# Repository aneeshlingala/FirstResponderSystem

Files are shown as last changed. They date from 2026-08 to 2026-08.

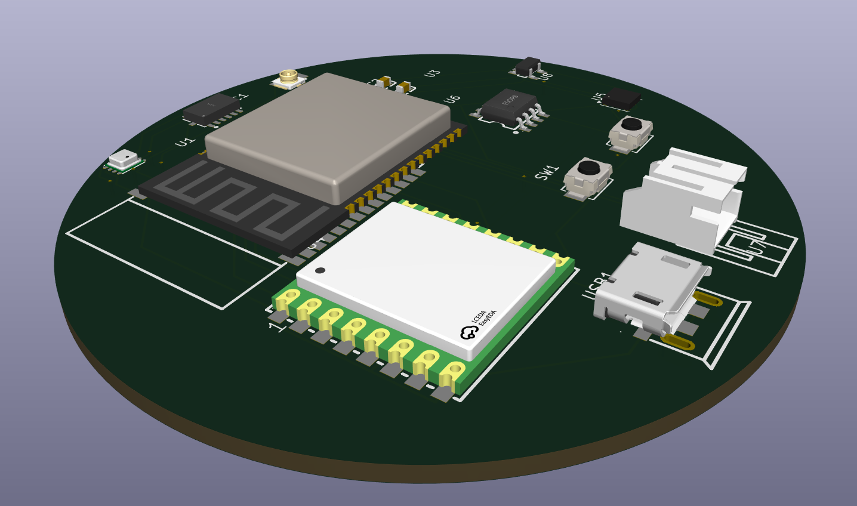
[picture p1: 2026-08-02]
environmentalnode/pcb_images/pcb3d.png

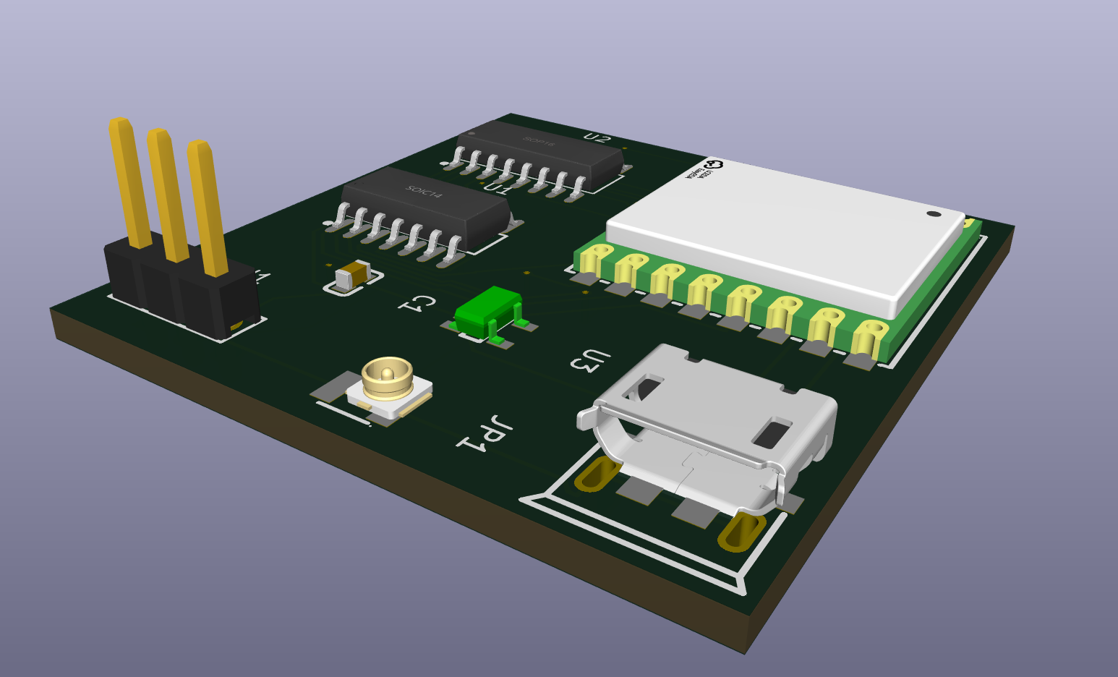
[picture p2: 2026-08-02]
broadcastnode/pcb_images/pcb3d.png

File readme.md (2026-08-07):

### Tech Report Link: [https://github.com/aneeshlingala/FirstResponderSystem/blob/main/tech_report_reverie_hacks_final.pdf](https://github.com/aneeshlingala/FirstResponderSystem/blob/main/tech_report_reverie_hacks_final.pdf)

# PROBLEM
During major disasters, first responders (police, fire, medical) do not have a reliable way to track their environment, find survivors, and receive information in real time. Existing systems can be expensive, hard to deploy, or require additional personnel to operate, wasting manpower that can be used from more urgent tasks.

# SOLUTION
The FirstResponderSystem uses cheap to manufacture, durable, and easy-to-deploy custom-made PCBs that create a centralized long-range radio network suited for emergencies instead of relying on broken or buggy connection systems (WiFi, Mobile Data, etc). By providing real-time sensor data and survivor detection, FirstResponderSystem allows emergency personnel to analyze dangerous conditions, locate any survivors, and make safe decisions while allowing responders to work on more urgent things. The data can also be sent to other organizations to relay information to people in the area, declare evacuations/emergencies, and more. The survivor node can be put in rubble to detect survivors, while the environmental node can be put in various parts of the disaster area. Multiple survivor and environmental nodes can be used at once. 

# CONTENTS OF GITHUB REPO
1. Survivor PCB
   * This PCB utilizes the cheap ATTINY16-14 MCU and utilizes Doppler Radars, Distance Sensors, and Infrared cameras to detect survivors trapped under rubble or other items. It broadcasts its data using an RFM95W LoRa transceiver (receiver and transmitter) on 915mHz. It is battery powered and uses a u.FL port for the antenna.

2. Environmental PCB
   * This PCB utilizes the cost-friendly ESP32 MCU and uses Bosch BME280 and BME680 Sensors to capture data about the environment. It also uses AQI, VOC, and other environmental sensors. It broadcasts its data using an RFM95W LoRa module on 915mHz, with a u.FL antenna port. It is battery powered.

3. Broadcast PCB
   * This PCB uses the cheap ATTINY16-14 MCU and receives data from the other two PCBS using the RFM95W LoRa transceiver. It takes the information received and sends it over Serial on Micro-USB to a computer to read. It is powered by the Micro-USB port.

4. Computer Software
   * The computer software includes a .py file for universal execution, as well as a .exe file generated by py2exe for quick use. The software is able to detect packets sent by the Broadcast PCB over serial and has an interface to select the COM port to read from. Once detected, it lists all the PCBS and shows info if you click on the names of the PCBS. It classifies the PCB as either ENV (environmental) or SRV (survivor detection). It shows all the info recorded by both PCBS. There is also a DEMO mode, which populates the user interface with "fake" broadcasting PCBS for showing at events or getting used to the interface.
  
# INFO

The PCBS were made in KiCAD 10 with footprints and symbols from LCSC, bundled KiCAD files, and SnapEDA.

All of the PCBS come with images:
* Image of the schematic
* Image of the PCB top-down
* Image of the PCB in 3D view

All of the PCBS come with code made in PlatformIO in VSCode. The programming language used to make the code is C++. The code successfully compiles with the firmware file in the .pio/build/[MCU NAME]/ and uses a good amount of 3rd-party libraries to interface with various components. 

The folders inside the survivornode, broadcastnode, or environmental node are structured as follows:
* The pcb_code folder includes the PCB Code written in C++.
* The pcb_images folder includes images of the schematic, PCB top-down, and the PCB in 3D.
* The pcb_data folder includes KiCAD files for opening the PCB in KiCAD. It also includes the Bill of Materials (BOM) and component positions CSV as well as the Gerber files in a zip.

The computer_code folder has a reciever.exe file for running on Windows without any dependencies being required to be installed. The reciever.py file can be run universally and requires Tkinter (already installed on most Python distributions), pyserial, and Python 3.13+ to run.

# WHAT I LEARNED
I learned how to make PCBs in KiCad 10 with proper symbols and footprints. I also learned how to use the design and electrical rules checker to make sure my project met all of the rules.

# CHALLENGES I FACED
Some challenges I faced included having issues with footprint/symbol quality, finding proper footprints for some of my component choices, and exporting gerbers. I solved these issues by searching up solutions online and using external plugins to export gerbers properly since it was bugged out with LCSC symbols. 

# DIAGRAM
DiagramFirstResponderSystem

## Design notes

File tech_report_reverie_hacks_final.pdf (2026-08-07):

Reverie Hacks 2026 Submission - Embedded Systems: https://github.com/aneeshlingala/FirstResponderSystem

## 1. Introduction

Abstract:
The FirstResponderSystem is an affordable LoRa based sensor network that allows first responders (police, fire, medical) to quickly find survivors and monitor their environment and hazards without relying on spotty or weak Wi-Fi or cell infrastructure.

The Problem:
During major disasters, first responders do not have a reliable way to track their environment, find survivors, and receive information in real time. A report from the Federal Communications Commission (FCC) during 2018 showed that natural disasters like Hurricanes Irma and Maria took down over 95% of cell infrastructure, affecting vital systems such as 911 call centers (Federal Communications Commission, 2018). Existing systems can be expensive, hard to deploy, or require additional personnel to operate, wasting manpower that can be used from more urgent tasks.

The Solution:
The FirstResponderSystem uses inexpensive, durable, and easy-to-deploy custom-made PCBs that create a centralized long-range radio network suited for emergencies instead of relying on broken or buggy connection systems (WiFi, Mobile Data, etc). LoRa has been shown to maintain good connectivity around ~3km in dense, suburban areas with an antenna mounted only a few meters off the ground (Augustin et al., 2016). By providing real-time sensor data and survivor detection, FirstResponderSystem allows emergency personnel to analyze dangerous conditions, locate any survivors, and make safe decisions while allowing responders to work on more urgent things. The data can also be sent to other organizations to relay information to people in the area, declare evacuations/emergencies, and more. The survivor node can be put in rubble to detect survivors, while the environmental node can be put in various parts of the disaster area. Multiple survivor and environmental nodes can be used at once.

Node Architecture Diagram:

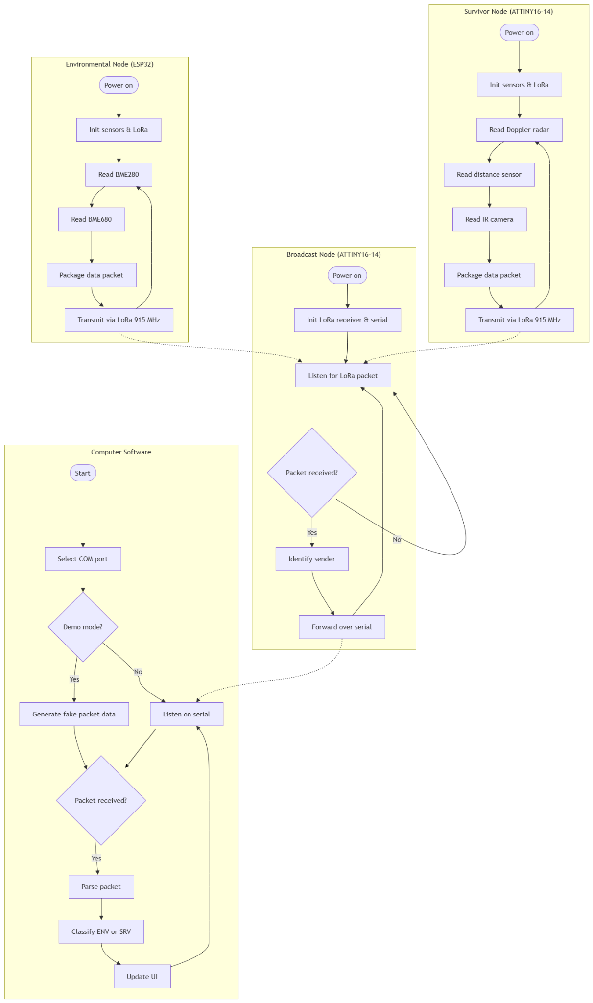
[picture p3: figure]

## 2.System Architecture

PCB and Software Interaction:
FirstResponderSystem runs as a centralized sensor network with three different hardware nodes and computer software to analyze the data. The system utilizes LoRa radios to transceive information without relying on WiFi or cell towers which may fail.
1. Survivor Node (SRV) and Environmental Node (ENV): The Survivor Node and Environmental Node operate by themselves with a battery. Multiple Survivor and Environmental nodes can be deployed in the disaster region. Survivor Nodes can be placed into rubble where survivors may be trapped, while Environmental Nodes can be deployed anywhere with an open area. Each node gets sensor readings, interprets and analyzes the data, makes a data packet, and transmits the data over the 915mHz band.
2. Broadcast Node: The Broadcast Node connects to a computer over Micro-USB to power itself and send data. Only one Broadcast Node can be deployed. It utilizes a LoRa radio transceiver to receive data packets from other independent nodes and uses a serial to USB converter to send data to the computer it is connected to.
3. Computer Software: The computer software acts as the layer between the data packets and human-readable information. It listens to serial packets sent by the Broadcast Node on a COM port, parses every packet and classifies it as SRV or ENV with the node’s randomly-generated identification number. It maintains a list of alerts and information from each node to be able to view the readings. The software also includes a “DEMO” mode, where the user interface is populated with fake nodes to show the functionalities of the software and let the users get acquainted with the interface.

Node Requirements:
Survivor and Environmental Nodes are required to be in range of the broadcast node to properly work. The computer software can alert if a node is having connection problems. New nodes can be added without needing to configure anything, allowing for quick deployment of more nodes if required.

## 3.Communication Specifications

Radio Specs:
All three nodes utilize the RFM95W LoRa transceiver (receiver + transmitter) with the Semtech SX1276 chipset. The LoRa radio technology was chosen because it had low power usage and long range when compared to WiFi or cellular.
﹣ Frequency: 915 mHz in ISM band
﹣ Transmit Power: +2 dBm to +20 dBm
﹣ Spreading Factor (higher - longer range, slower transmission, vice versa): SF9
﹣ Expected Range: 5-20km (depends on tuning)
﹣ Data Rate: ~1.8 kbps
﹣ Antenna: u.FL (https://en.wikipedia.org/wiki/Hirose_U.FL) connector to attach an antenna
﹣ Survivor Node Packet Format: RSSI:<rssi>,SNR:<snr>,DATA:ID:<node_id>,X:<x>,Y:<y> ,Z:<z>,M:<motion>,P:<presence>,D:<distance>,H:<huma n>
﹣ Environmental Node Packet Format: RSSI:<rssi>,SNR:<snr>,DATA:Node ID:<node_id>,Temp:<temp>,Pressure:<pressure>,Humidi ty:<humidity>,X gyro:<x>,Y gyro:<y>,Z gyro:<z>,Gas temp:<gas_temp>,VOC:<voc>

## 4.Software

Computer Software Info:
The computer software (client) is built for Python 3.11+ and utilizes Tkinter for the GUI part of the client. It uses pyserial to interface with the COM ports and receive serial data. It can be used without needing to install dependencies on Windows computers when the .exe is run. The .exe was built with py2exe. For usage on other operating systems, the .py file can be used. However, there needs to be Python 3.11+, Tkinter (provided with most Python software distributions), and the pyserial module installed.

Serial Reader:
A background process called serial_reader opens the selected COM port at 115200 baud rate. Each line from the serial input is pushed onto an info queue and is refreshed to show on the screen every 300ms.

Packet Parsing:
Each line utilizes a comma delimitated format. The software is able to differentiate node type by the start of the packet, where it either says it is under ENV (environmental) or SRV (survivor). This keeps the data format more human-readable when debugging is required.

Node Tracking:
Each node’s sensor data is saved in memory, allowing for a rolling history of sensor outputs. The sensor data is either shown in text or in a live chart to the user. Nodes are either in the online state, stale state (no packet in 15sec), or offline state (no packet in 60sec). These switching states allow for capturing and reading accurate data and alerts.

Alerts:
The software has three varying levels of alerts: info, warning, and critical. These alerts can be triggered by human presence detection, RSSI (signal strength) dropping below -95dBm, or a node going stale or offline.

Demo Mode:
Demo mode runs a thread that simulates realistic data packets for various simulated nodes. The data packets are populated with randomly-generated info, allowing for demos of the software without having nodes on hand.

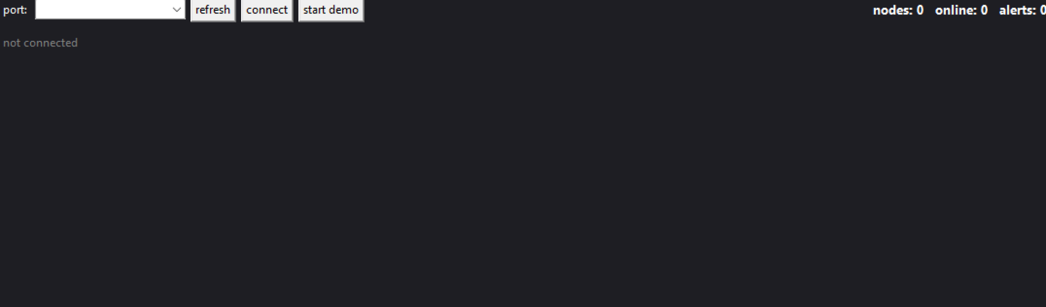
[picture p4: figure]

## 5.PCB Design

Details:
All of the three nodes were custom-designed in KiCAD 10 as a double layer board. The footprints and symbols used in the PCBs were from LCSC, already bundled in KiCAD, or RCWL/SnapEDA.

Survivor Node PCB:
﹣ MCU: ATTINY16-14
﹣ Key Components: Doppler radar, distance sensor, IR camera, and RFM95W LoRa transceiver
﹣ Size: 75 x 56mm
﹣ Power: Battery-powered Li-ion
﹣ Cost: $11-12 per PCB + parts cost

Environmental Node PCB:
﹣ MCU: ESP32
﹣ Key components: BME280, BME680, and RFM95W LoRa transceiver
﹣ Size: Circular - 62.17 x 62.17mm
﹣ Power: Battery-powered Li-ion
﹣ Cost: $7-8 per PCB + parts cost

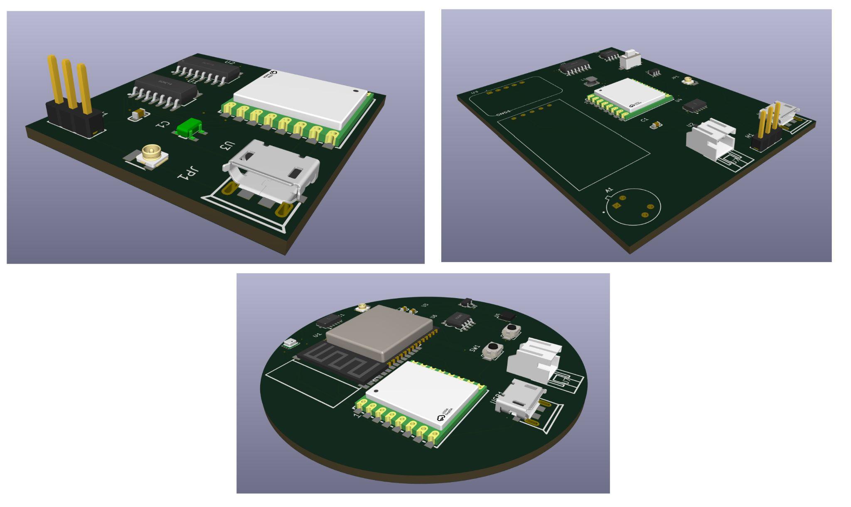
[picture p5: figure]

Broadcast Node PCB:
﹣ MCU: ATTINY16-14
﹣ Key components: RFM95W LoRa transceiver, and Micro-USB port ﹣ Size: 34.76 x 35.98mm
﹣ Power: Micro-USB Port
﹣ Cost: $5.50-7.00 per PCB + parts cost

Design Considerations:
For the MCU, the ATTINY16-14 was chosen for the Survivor Node because it was a chip that could last long on batteries while still being able to get proper data from its sensors. For the environmental node, the ESP32 was chosen because it had better compatibility and power for more complex sensors, while still conserving battery. For the Broadcast Node, the ATTINY16-14 was chosen because the components and purpose of the PCB were simple

## 6.Testing

Status:
As of now, this project has been digitally tested and validated in every phase that doesn’t require PCB fabrication.

What has been validated:
﹣ Schematic and layout was tested using KiCAD’s electrical rules checker
﹣ PCB was tested using KiCAD’s design rules checker
﹣ Computer software was tested by sending packets matching the expected format over serial
﹣ Firmware code was able to compile and could fit under the flash storage limit of the MCU

What needs to be done:
﹣ Fabrication and assembly of the PCBS (either by hand-soldering or PCBA)
﹣ LoRa range testing
﹣ Packet reliability over varying distances
﹣ Battery life testing

## 7.Sustainability and Scalability

Cost and Deployment:
Each PCB is very inexpensive to make (about $1-2 per PCB - excluding parts), making FirstResponderSystem much affordable to deploy at scale compared to other similar systems like SAR equipment or thermal drones. Nodes are also redeployable if they aren’t too damaged.

Network Scalability:
FirstResponderSystem utilizes a star topology, so new Survivor and Environmental Nodes can be added to the system without needing a full system reconfiguration or restart. The system runs on a two-second transmit interval and runs at SF9 spreading factor, allowing one broadcast node to receive data from dozens of nodes without slowing down or getting too overloaded.

Environmental Impact:
The nodes were programmed to only transmit briefly and infrequently compared to having a constant connection to WiFi networks or cell towers. This way of sending packets allows the nodes to conserve power and maintain a low RF footprint. Since components are soldered, either by stencil or by hand, bad or damaged components can be replaced rather than discarding the whole node.

## 8. Programming

Firmware Language and Tools Used:
All three nodes were programmed in C++ using PlatformIO Arduino in Visual Studio Code. The code is organized with its own platformio.ini, source code files, and libraries. The code was verified to compile successfully and fit within the boundaries of the flash storage size.

Fitting within flash storage boundaries:
The Survivor and Broadcast nodes run on the ATTINY16-14 MCU, which only has 16 KB of flash. Few vendor libraries were too big to fit when compiled with the LoRa and sensor libraries. A few examples of these libraries included RadioLib (on some nodes) and the MLX90640 library. To combat this issue, the SX1276 library was used instead of RadioLib to directly interface with the chip, and it was lighter since it did not carry configurations for other chips. Similarly, the MLX90640 library was replaced with a custom I2C driver integrated into the code that interfaced with registers to work, rather than pulling full driver libraries like other libraries would do. This method was utilized because disabling specific parts of libraries in platformio.ini was breaking dependencies and library functionality overall, especially for RadioLib. Manual string-building was also used to save flash storage rather than using heavy string libraries.

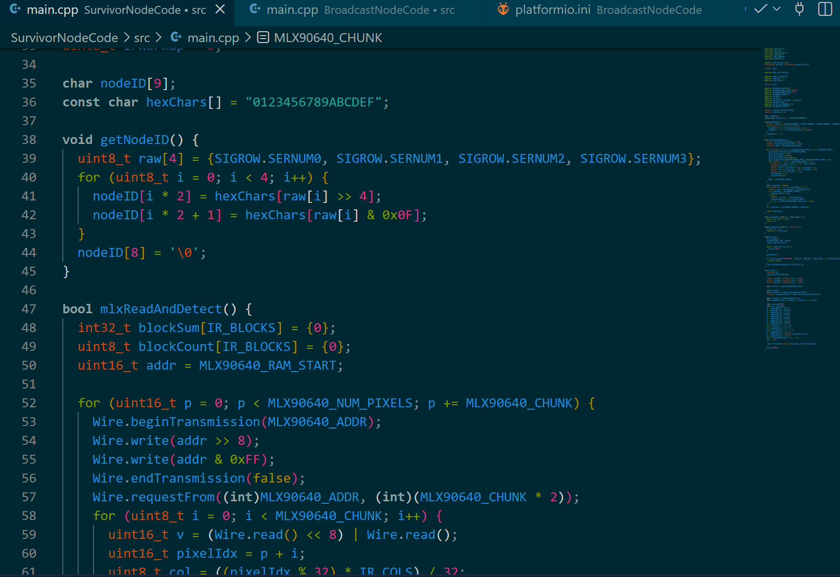
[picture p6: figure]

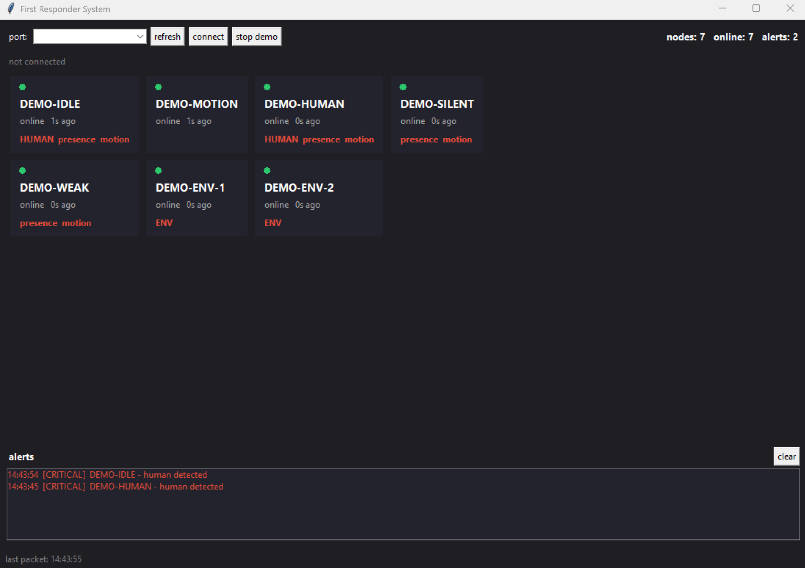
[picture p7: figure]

## 9. User Experience and Design

Computer Software UI:
Since first responders need to interpret data quickly under stressful conditions, the software’s user interface (UI) was designed to be human-readable and viewable at-a-glance while still preserving information. Another principle that was used in the creation of the UI was that a first responder should be able to tell the condition and alerts from a node, without needing to parse the sensor values themselves.

At-a-glance Status:
In the UI box of a node, a color-coded status (online, stale, offline) is shown so connection issues can be noticed without reading logs or timestamps. Alerts are also classified with three levels, with info, warning, and critical. This allows a first responder to quickly locate a major issue without digging through a list of other issues or logs.

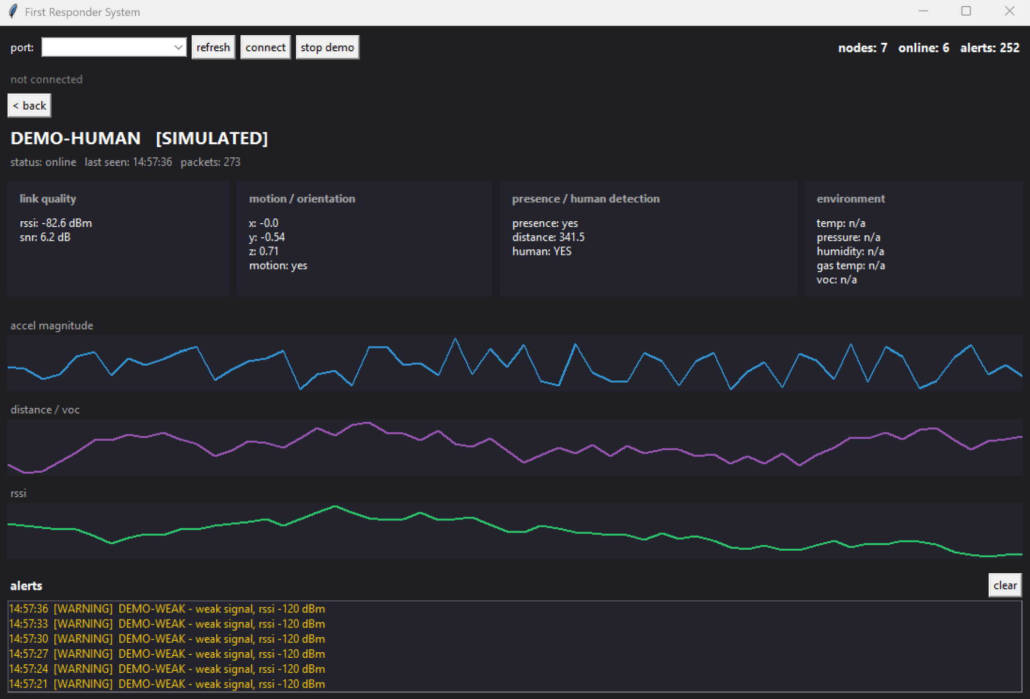
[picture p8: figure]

No Configuration Required:
New nodes are able to automatically join the list in the computer once they are detected. Since information is sent over serial and the nodes utilize a star-topology, there is no need to waste time setting up nodes, naming the nodes, or manually pairing. Nodes can easily be added on-the-fly without needing any special technicians or specialized people, since they automatically generate a name from information in the MCU’s fuses.

No-Hardware Preview:
Demo mode in the computer software allows first responders or judges to get familiar with the interface. Demo mode populates the interface with “fake” nodes that send randomly-generated packets to simulate disasters/incidents. This mode can also show the software at events without needing systems or nodes on hand.

## 10. Future Improvements

Things to be done:
- Data Logging - Save incoming packets into a database (online or locally) for future analysis

- Packet Resending - Make a node resend a packet if it was dropped or information was lost
- Encryption/Auth - Add authentication and encryption to the packets to keep information safe
- GPS - Add GPS to the Survivor and Environmental Nodes so that the nodes show detections on a map, not a list
- Mobile/Web interface - Expand the Tkinter interface to allow first responders to view info from a phone or web browser
- Adjust frequency based on region - Different countries and parts of the world use different frequencies for LoRa/unlicensed bands, so we need to ship different modems for each region of the world
- FCC Part 15 Compliance - Any deployment of the FirstResponderSystem would require compliance with FCC Part 15’s transmit power, duty cycle, and frequency hopping regulations

## 11. Team and Credits

Creator Info:
This project was designed, built, and recorded by Aneesh Lingala.

Acknowledgements (names ending in .h are C or C++ libraries):
- KiCAD for the PCB designing software
- Arduino.h - Arduino Core Team
- Wire.h - Arduino Core Team
- SX1276.h - Matthias Prinke
- ADXL345_WE.h - Wolfgang Ewald
- LD2410.h - Nick Reynolds
- Bosch_BME280_Arduino.h - Frank Häfele
- Zanshin_BME680.h - SV-Zanshin Arduino Org.
- Radiolib.h (Environmental Node) - Jan Gromeš
- WiFi.h (ESP32) - Espressif Systems
- PySerial (computer software) - Chris Liechti
- Tkinter (computer software) - Guido van Rossum and Steen Lumholt

Works Cited:

- Federal Communications Commission, Public Safety and Homeland Security Bureau. (2018). 2017 Atlantic hurricane season: Impact on communications report and recommendations (Public Safety Docket No. 17-344).
https://docs.fcc.gov/public/attachments/DOC-353805A1.pdf
- Augustin, A., Yi, J., Clausen, T., & Townsley, W. (2016). A study of LoRa: Long range & low power networks for the internet of things. Sensors, 16(9), 1466. https://doi.org/10.3390/s16091466

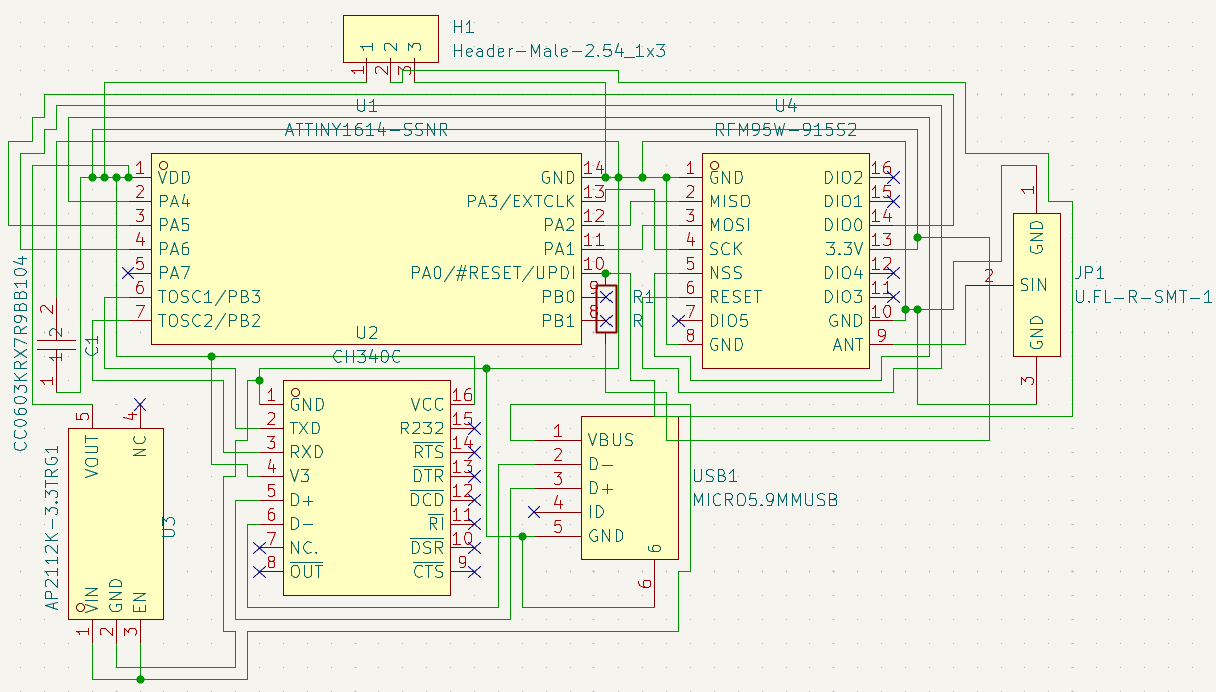
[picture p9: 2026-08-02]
broadcastnode/pcb_images/schematic.png

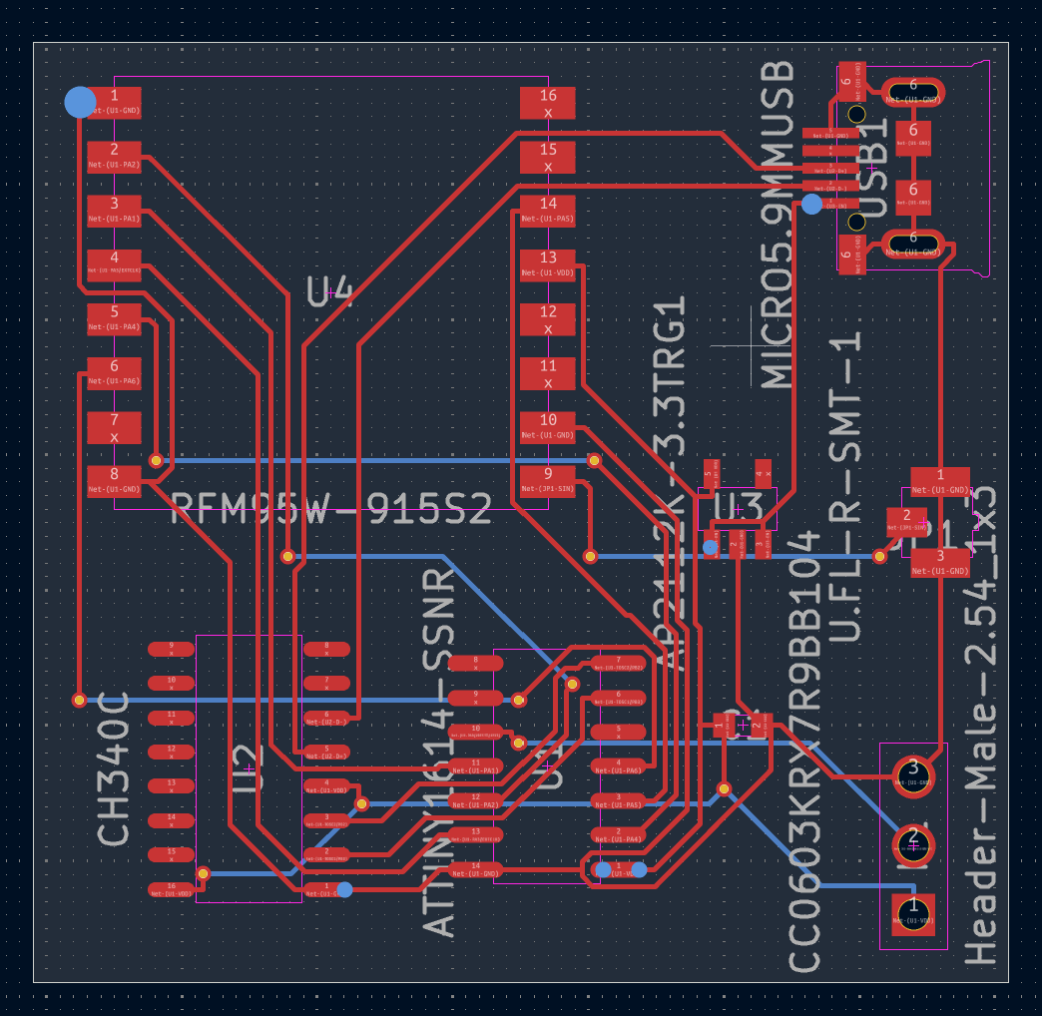
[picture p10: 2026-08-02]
broadcastnode/pcb_images/pcbtopdown.png

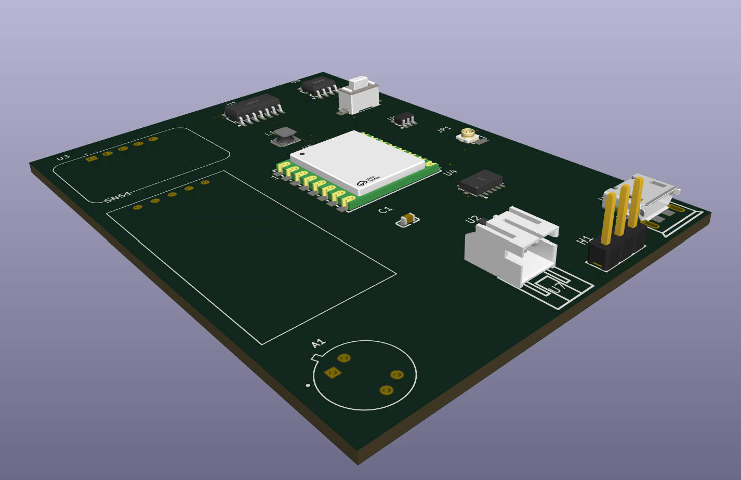
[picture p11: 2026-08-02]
survivornode/pcb_images/pcb3d.png

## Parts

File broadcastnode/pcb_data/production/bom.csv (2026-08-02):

Designator | Footprint | Quantity | Value | LCSC Part #
C1 | C0603 | 1 | CC0603KRX7R9BB104 | C14663
H1 | HDR-TH_3P-P2.54-V-M-1 | 1 | Header-Male-2.54_1x3 | C49257
JP1 | ANT-SMD_UFL-R-SMT-1-10 | 1 | U.FL-R-SMT-1 | C88373
U1 | SOIC-14_L8.7-W3.9-P1.27-LS6.0-BL | 1 | ATTINY1614-SSNR | C481364
U2 | SOP-16_L10.0-W3.9-P1.27-LS6.0-BL | 1 | CH340C | C84681
U3 | SOT-25-5_L2.9-W1.6-P0.95-LS2.8-BL | 1 | AP2112K-3.3TRG1 | C51118
U4 | WIRELM-SMD_16P-L16.0-W16.0-P2.00_LORA-CC68-915MHZ-TCXO | 1 | RFM95W-915S2 | C6760738
USB1 | MICRO-USB-SMD_5P-P0.65-H-F_MICRO5.9MMUSB | 1 | MICRO5.9MMUSB | C393940

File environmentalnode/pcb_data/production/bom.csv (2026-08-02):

Designator | Footprint | Quantity | Value | LCSC Part #
C1 | C0603 | 1 | CC0603KRX7R9BB104 | C14663
C2 | C0603 | 1 | CL10A105KB8NNNC | C15849
JP1 | ANT-SMD_UFL-R-SMT-1-10 | 1 | U.FL-R-SMT-1 | C88373
SW1, SW2 | SW-SMD_L3.9-W3.0-P4.45 | 2 | TS-1088-AR02016 | C720477
U1 | WIFI-SMD_ESP32-WROOM-32E | 1 | ESP32-WROOM-32E | C701342
U2 | LGA-8_BME280_BL | 1 | BME280 | C92489
U3 | LGA-14_L5.0-W3.0-P0.80-BL | 1 | ADXL345BCCZ-RL7 | C9667
U4 | WIRELM-SMD_16P-L16.0-W16.0-P2.00_LORA-CC68-915MHZ-TCXO | 1 | RFM95W-915S2 | C6760738
U5 | Bosch_LGA-8_3x3mm_P0.8mm_ClockwisePinNumbering | 1 | BME680
U6 | ESOP-8_L4.9-W3.9-P1.27-LS6.0-BL-EP | 1 | TP4056 | C16581
U7 | CONN-TH_S2B-PH-K-S-LF-SN | 1 | S2B-PH-K-S | C173752
U8 | SOT-25-5_L2.9-W1.6-P0.95-LS2.8-BL | 1 | AP2112K-3.3TRG1 | C51118
USB1 | MICRO-USB-SMD_5P-P0.65-H-F_MICRO5.9MMUSB | 1 | MICRO5.9MMUSB | C393940

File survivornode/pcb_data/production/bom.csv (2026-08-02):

Designator | Footprint | Quantity | Value | LCSC Part #
A1 | TO292P930H600-4 | 1 | MLX90640ESF-BAA-000-TU
C1 | C0603 | 1 | CL10A105KB8NNNC | C15849
H1 | HDR-TH_3P-P2.54-V-M-1 | 1 | Header-Male-2.54_1x3 | C49257
JP1 | ANT-SMD_UFL-R-SMT-1-10 | 1 | U.FL-R-SMT-1 | C88373
L1 | IND-SMD_L3.0-W3.0_FNR30XXS | 1 | FNR3015S2R2MT | C167747
SNS1 | RCWL-0516 | 1 | RCWL-0516
U1 | SOIC-14_L8.7-W3.9-P1.27-LS6.0-BL | 1 | ATTINY1614-SSNR | C481364
U2 | SOT-563_L1.6-W1.2-P0.50-LS1.6-BR | 1 | TPS61023DRLR | C919459
U3 | MODULE_HLK-LD2410C | 1 | HLK-LD2410C
U4 | LGA-14_L5.0-W3.0-P0.80-BL | 1 | ADXL345BCCZ-RL7 | C9667
U5 | WIRELM-SMD_16P-L16.0-W16.0-P2.00_LORA-CC68-915MHZ-TCXO | 1 | RFM95W-915S2 | C6760738
U6 | SW-SMD_L6.0-W3.5-LS8.0 | 1 | YZA-032-5.0W | C49108628
U7 | CONN-TH_S2B-PH-K-S-LF-SN | 1 | S2B-PH-K-S | C173752
U8 | ESOP-8_L4.9-W3.9-P1.27-LS6.0-BL-EP | 1 | TP4056 | C16581
U9 | SOT-25-5_L2.9-W1.6-P0.95-LS2.8-BL | 1 | AP2112K-3.3TRG1 | C51118
USB1 | MICRO-USB-SMD_5P-P0.65-H-F_MICRO5.9MMUSB | 1 | MICRO5.9MMUSB | C393940

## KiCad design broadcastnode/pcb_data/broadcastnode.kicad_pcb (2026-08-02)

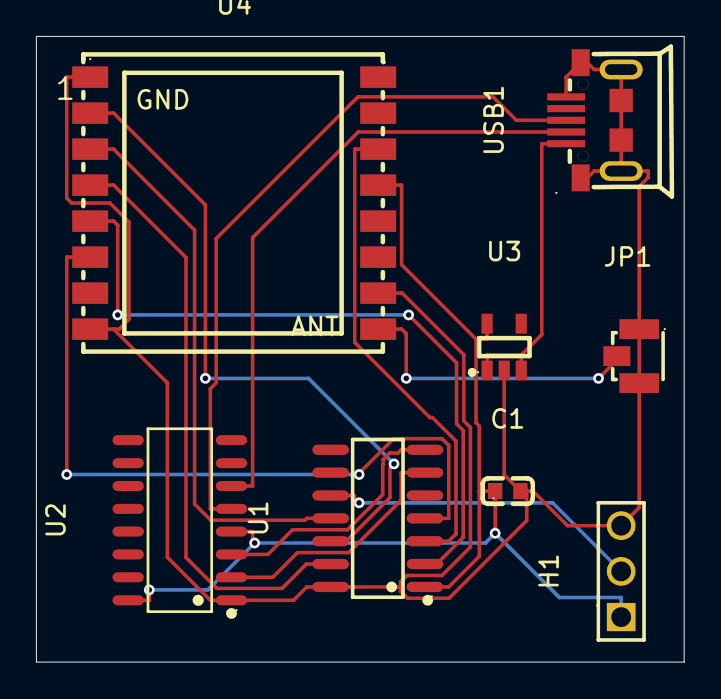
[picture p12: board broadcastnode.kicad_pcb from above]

Board: 2 copper layers, 36.0 x 34.8 mm, 8 parts (0 on the bottom side), 15 nets.

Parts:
C1: CC0603KRX7R9BB104; C0603
H1: Header-Male-2.54_1x3; HDR-TH_3P-P2.54-V-M-1
JP1: U.FL-R-SMT-1; ANT-SMD_UFL-R-SMT-1-10
U1: ATTINY1614-SSNR; SOIC-14_L8.7-W3.9-P1.27-LS6.0-BL
U2: CH340C; SOP-16_L10.0-W3.9-P1.27-LS6.0-BL
U3: AP2112K-3.3TRG1; SOT-25-5_L2.9-W1.6-P0.95-LS2.8-BL
U4: RFM95W-915S2; WIRELM-SMD_16P-L16.0-W16.0-P2.00_LORA-CC68-915MHZ-TCXO
USB1: MICRO5.9MMUSB; MICRO-USB-SMD_5P-P0.65-H-F_MICRO5.9MMUSB

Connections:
unnamed: JP1.2 (SIN), U4.9 (ANT)
unnamed: C1.2, H1.3, JP1.1 (GND), JP1.3 (GND), U1.14 (GND), U2.1 (GND), U3.2 (GND), U4.1 (GND), U4.8 (GND), U4.10 (GND), USB1.5 (GND), USB1.6
unnamed: H1.2, U1.10 (PA0/#RESET/UPDI)
unnamed: U1.11 (PA1), U4.3 (MOSI)
unnamed: U1.12 (PA2), U4.2 (MISO)
unnamed: U1.13 (PA3/EXTCLK), U4.4 (SCK)
unnamed: U1.2 (PA4), U4.5 (NSS)
unnamed: U1.3 (PA5), U4.14 (DIO0)
unnamed: U1.4 (PA6), U4.6 (RESET)
unnamed: U1.6 (TOSC1/PB3), U2.2 (TXD)
unnamed: U1.7 (TOSC2/PB2), U2.3 (RXD)
unnamed: C1.1, H1.1, U1.1 (VDD), U2.4 (V3), U2.16 (VCC), U3.5 (VOUT), U4.13 (3.3V)
unnamed: U2.5 (D+), USB1.3 (D+)
unnamed: U2.6 (D-), USB1.2 (D-)
unnamed: U3.1 (VIN), U3.3 (EN), USB1.1 (VBUS)

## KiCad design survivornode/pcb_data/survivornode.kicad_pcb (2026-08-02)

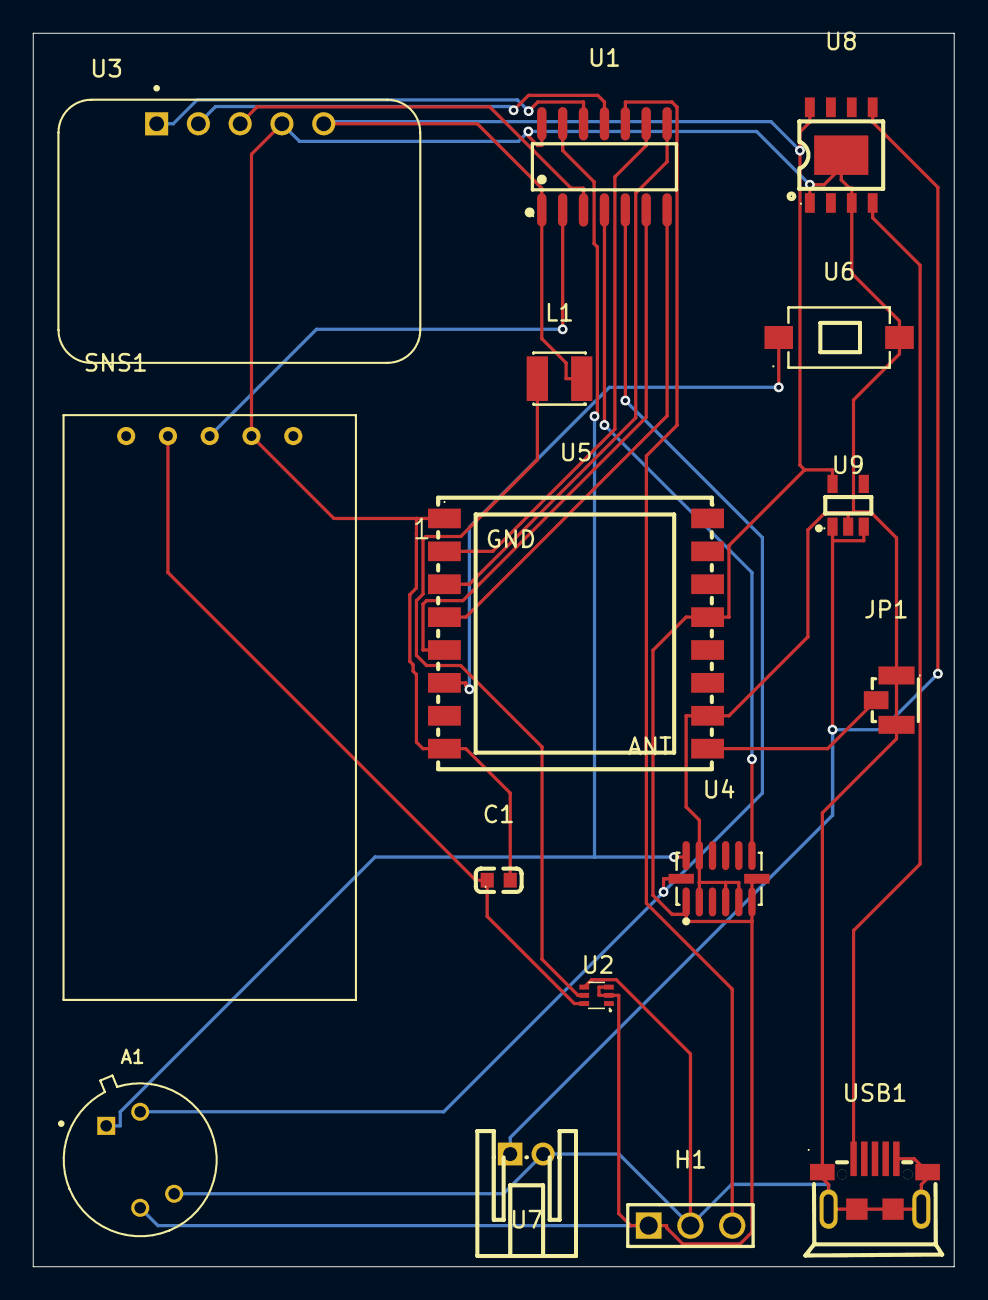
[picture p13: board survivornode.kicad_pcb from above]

Board: 2 copper layers, 56.0 x 75.0 mm, 16 parts (0 on the bottom side), 20 nets.

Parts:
A1: MLX90640ESF-BAA-000-TU; TO292P930H600-4
C1: CL10A105KB8NNNC; C0603
H1: Header-Male-2.54_1x3; HDR-TH_3P-P2.54-V-M-1
JP1: U.FL-R-SMT-1; ANT-SMD_UFL-R-SMT-1-10
L1: FNR3015S2R2MT; IND-SMD_L3.0-W3.0_FNR30XXS
SNS1: RCWL-0516
U1: ATTINY1614-SSNR; SOIC-14_L8.7-W3.9-P1.27-LS6.0-BL
U2: TPS61023DRLR; SOT-563_L1.6-W1.2-P0.50-LS1.6-BR
U3: HLK-LD2410C; MODULE_HLK-LD2410C
U4: ADXL345BCCZ-RL7; LGA-14_L5.0-W3.0-P0.80-BL
U5: RFM95W-915S2; WIRELM-SMD_16P-L16.0-W16.0-P2.00_LORA-CC68-915MHZ-TCXO
U6: YZA-032-5.0W; SW-SMD_L6.0-W3.5-LS8.0
U7: S2B-PH-K-S; CONN-TH_S2B-PH-K-S-LF-SN
U8: TP4056; ESOP-8_L4.9-W3.9-P1.27-LS6.0-BL-EP
U9: AP2112K-3.3TRG1; SOT-25-5_L2.9-W1.6-P0.95-LS2.8-BL
USB1: MICRO5.9MMUSB; MICRO-USB-SMD_5P-P0.65-H-F_MICRO5.9MMUSB

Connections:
unnamed: A1.3 (GND), C1.2, H1.2, JP1.1 (GND), JP1.3 (GND), SNS1.GND, U1.14 (GND), U2.4 (GND), U3.4 (GND), U4.2 (GND), U4.4 (GND), U4.5 (GND), U4.12 (SDO/ALTADDRESS), U5.1 (GND), U5.8 (GND), U5.10 (GND), U6.2, U7.2, U8.1 (TEMP), U8.3 (GND), U8.9 (EP), U9.2 (GND), USB1.5 (GND), USB1.6
unnamed: A1.4 (SCL), U1.5 (PA7), U4.14 (SCL/SCLK)
unnamed: A1.1 (SDA), U1.13 (PA3/EXTCLK), U4.13 (SDA/SDI/SDIO)
unnamed: A1.2 (VDD), H1.1, L1.1, U1.1 (VDD), U2.2 (EN), U2.3 (VIN), U3.5 (VCC), U4.1 (VDDIO), U4.6 (VS), U4.7 (~CS), U5.13 (3.3V), U8.8 (CE), U9.5 (VOUT)
unnamed: JP1.2 (SIN), U5.9 (ANT)
unnamed: H1.3, U1.10 (PA0/#RESET/UPDI)
unnamed: U1.11 (PA1), U3.2 (UART_RX)
unnamed: U1.12 (PA2), U3.1 (UART_TX)
unnamed: SNS1.OUT, U1.2 (PA4)
unnamed: U1.3 (PA5), U3.3 (OUT)
unnamed: U1.4 (PA6), U4.8 (INT1)
unnamed: U1.9 (PB0), U5.2 (MISO)
unnamed: U1.8 (PB1), U5.3 (MOSI)
unnamed: U1.6 (TOSC1/PB3), U5.5 (NSS)
unnamed: U1.7 (TOSC2/PB2), U5.4 (SCK)
unnamed: L1.2, U2.5 (SW)
unnamed: C1.1, SNS1.VIN, U2.6 (VOUT)
unnamed: U5.6 (RESET), U6.1
unnamed: U7.1, U8.5 (BAT), U9.1 (VIN), U9.3 (EN)
unnamed: U8.4 (VCC), USB1.1 (VBUS)

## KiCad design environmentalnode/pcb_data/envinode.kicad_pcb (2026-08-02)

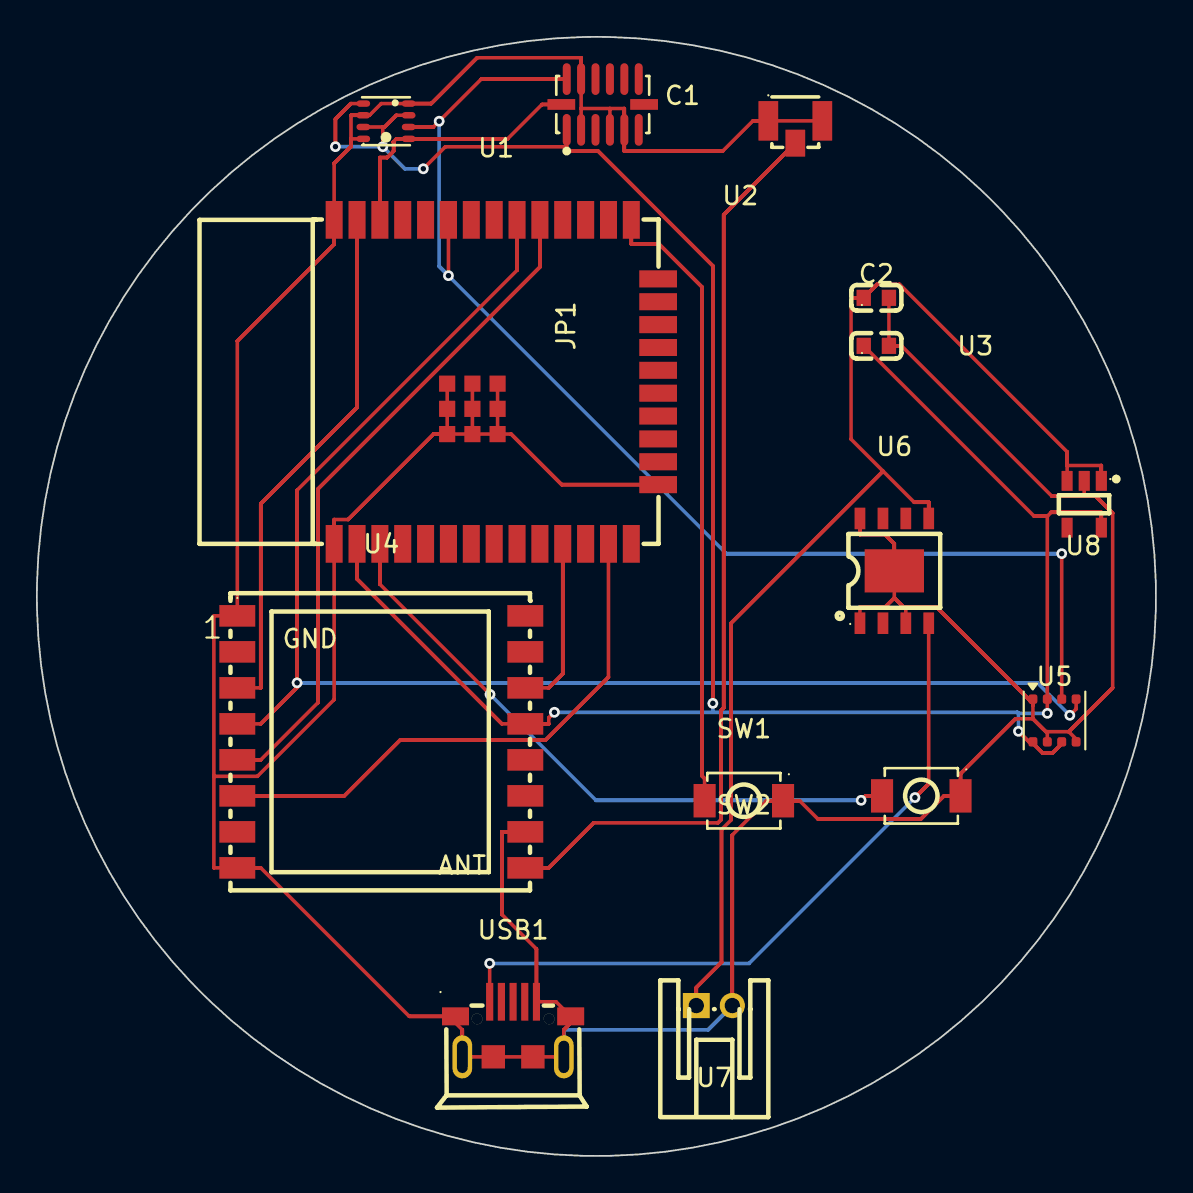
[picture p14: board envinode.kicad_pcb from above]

Board: 2 copper layers, 62.2 x 62.2 mm, 14 parts (0 on the bottom side), 15 nets.

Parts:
C1: CC0603KRX7R9BB104; C0603
C2: CL10A105KB8NNNC; C0603
JP1: U.FL-R-SMT-1; ANT-SMD_UFL-R-SMT-1-10
SW1, SW2: TS-1088-AR02016; SW-SMD_L3.9-W3.0-P4.45
U1: ESP32-WROOM-32E; WIFI-SMD_ESP32-WROOM-32E
U2: BME280; LGA-8_BME280_BL
U3: ADXL345BCCZ-RL7; LGA-14_L5.0-W3.0-P0.80-BL
U4: RFM95W-915S2; WIRELM-SMD_16P-L16.0-W16.0-P2.00_LORA-CC68-915MHZ-TCXO
U5: BME680; Bosch_LGA-8_3x3mm_P0.8mm_ClockwisePinNumbering
U6: TP4056; ESOP-8_L4.9-W3.9-P1.27-LS6.0-BL-EP
U7: S2B-PH-K-S; CONN-TH_S2B-PH-K-S-LF-SN
U8: AP2112K-3.3TRG1; SOT-25-5_L2.9-W1.6-P0.95-LS2.8-BL
USB1: MICRO5.9MMUSB; MICRO-USB-SMD_5P-P0.65-H-F_MICRO5.9MMUSB

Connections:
unnamed: JP1.2 (SIN), U4.9 (ANT)
unnamed: C2.1, U1.2 (3V3), U2.2 (CSB), U2.6 (VDDIO), U2.8 (VDD), U3.1 (VDDIO), U4.13 (3.3V), U5.2 (CSB), U5.5 (SDO), U5.6 (VDDIO), U5.8 (VDD), U8.5 (VOUT)
unnamed: SW2.1, U1.3 (EN)
unnamed: SW1.1, U1.25 (IO0)
unnamed: U1.29 (IO5), U4.5 (NSS)
unnamed: U1.13 (IO14), U4.6 (RESET)
unnamed: U1.30 (IO18), U4.4 (SCK), U5.4 (SCK)
unnamed: U1.31 (IO19), U4.2 (MISO)
unnamed: U1.33 (IO21), U2.3 (SDI), U3.13 (SDA/SDI/SDIO), U5.3 (SDI)
unnamed: U1.36 (IO22), U2.4 (SCK), U3.14 (SCL/SCLK)
unnamed: U1.37 (IO23), U4.3 (MOSI)
unnamed: U1.11 (IO26), U4.14 (DIO0)
unnamed: C1.2, C2.2, JP1.1 (GND), JP1.3 (GND), SW1.2, SW2.2, U1.1 (GND), U1.15 (GND), U1.38 (GND), U1.39 (GND), U2.1 (GND), U2.5 (SDO), U2.7 (GND), U3.2 (GND), U3.4 (GND), U3.5 (GND), U3.12 (SDO/ALTADDRESS), U4.1 (GND), U4.8 (GND), U4.10 (GND), U5.1 (GND), U5.7 (GND), U6.1 (TEMP), U6.3 (GND), U6.8 (CE), U6.9 (EP), U7.2, U8.2 (GND), USB1.5 (GND), USB1.6
unnamed: C1.1, U6.5 (BAT), U7.1, U8.1 (VIN), U8.3 (EN)
unnamed: U6.4 (VCC), USB1.1 (VBUS)

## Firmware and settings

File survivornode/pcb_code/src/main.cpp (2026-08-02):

#include <Arduino.h>
#include <Wire.h>
#include <ADXL345_WE.h>
#include <ld2410.h>
#define LORA_ENABLED
#include <SX1276.h>

#define ADXL345_I2C 0x53
ADXL345_WE adxl345 = ADXL345_WE(ADXL345_I2C);

ld2410 radar;

#define RCWL_PIN PIN_PA4

#define LORA_CS PIN_PB3
#define LORA_RST -1
#define LORA_DIO0 -1

SX1276 radio;

#define MLX90640_ADDR 0x33
#define MLX90640_RAM_START 0x0400
#define MLX90640_NUM_PIXELS 768
#define MLX90640_CHUNK 16
#define IR_ROWS 3
#define IR_COLS 4
#define IR_BLOCKS (IR_ROWS * IR_COLS)
#define IR_EMA_SHIFT 6
#define IR_DELTA_THRESHOLD 25
#define IR_WARMUP_FRAMES 5

int16_t irBaseline[IR_BLOCKS];
uint8_t irWarmup = 0;

char nodeID[9];
const char hexChars[] = "0123456789ABCDEF";

void getNodeID() {
  uint8_t raw[4] = {SIGROW.SERNUM0, SIGROW.SERNUM1, SIGROW.SERNUM2, SIGROW.SERNUM3};
  for (uint8_t i = 0; i < 4; i++) {
    nodeID[i * 2] = hexChars[raw[i] >> 4];
    nodeID[i * 2 + 1] = hexChars[raw[i] & 0x0F];
  }
  nodeID[8] = '\0';
}

bool mlxReadAndDetect() {
  int32_t blockSum[IR_BLOCKS] = {0};
  uint8_t blockCount[IR_BLOCKS] = {0};
  uint16_t addr = MLX90640_RAM_START;

  for (uint16_t p = 0; p < MLX90640_NUM_PIXELS; p += MLX90640_CHUNK) {
    Wire.beginTransmission(MLX90640_ADDR);
    Wire.write(addr >> 8);
    Wire.write(addr & 0xFF);
    Wire.endTransmission(false);
    Wire.requestFrom((int)MLX90640_ADDR, (int)(MLX90640_CHUNK * 2));
    for (uint8_t i = 0; i < MLX90640_CHUNK; i++) {
      uint16_t v = (Wire.read() << 8) | Wire.read();
      uint16_t pixelIdx = p + i;
      uint8_t col = ((pixelIdx % 32) * IR_COLS) / 32;
      uint8_t row = ((pixelIdx / 32) * IR_ROWS) / 24;
      uint8_t b = row * IR_COLS + col;
      blockSum[b] += v;
      blockCount[b]++;
    }
    addr += MLX90640_CHUNK;
  }

  bool detected = false;
  for (uint8_t b = 0; b < IR_BLOCKS; b++) {
    int16_t avg = blockSum[b] / blockCount[b];
    if (irWarmup < IR_WARMUP_FRAMES) {
      irBaseline[b] = avg;
    } else {
      int16_t d = avg - irBaseline[b];
      irBaseline[b] += d >> IR_EMA_SHIFT;
      if (d > IR_DELTA_THRESHOLD) detected = true;
    }
  }
  if (irWarmup < IR_WARMUP_FRAMES) irWarmup++;

  return detected;
}

char* appendStr(char* p, const char* s) {
  while (*s) *p++ = *s++;
  return p;
}

char* appendInt(char* p, int16_t v) {
  itoa(v, p, 10);
  return p + strlen(p);
}

void setup() {
  Wire.swap(1);
  pinMode(RCWL_PIN, INPUT);
  radar.begin(Serial);

  while (!adxl345.init()) {
    delay(2000);
  }

  getNodeID();

  if (radio.begin(915000000L, LORA_CS, LORA_RST, LORA_DIO0) != SX1276_ERR_NONE) {
    while (true);
  }
  radio.setSpreadingFactor(SX1276_SF_9);
}

void loop() {
  xyzFloat g;
  adxl345.getGValues(&g);

  int16_t gx100 = (int16_t)(g.x * 100);
  int16_t gy100 = (int16_t)(g.y * 100);
  int16_t gz100 = (int16_t)(g.z * 100);

  bool motion = digitalRead(RCWL_PIN);

  radar.read();
  bool presence = radar.presenceDetected();
  uint16_t targetDistance = radar.movingTargetDistance();

  bool irHuman = mlxReadAndDetect();
  bool humanDetected = irHuman || presence || motion;

  char payload[100];
  char* p = payload;
  p = appendStr(p, "ID:");
  p = appendStr(p, nodeID);
  p = appendStr(p, ",X:");
  p = appendInt(p, gx100);
  p = appendStr(p, ",Y:");
  p = appendInt(p, gy100);
  p = appendStr(p, ",Z:");
  p = appendInt(p, gz100);
  p = appendStr(p, ",M:");
  *p++ = motion ? '1' : '0';
  p = appendStr(p, ",P:");
  *p++ = presence ? '1' : '0';
  p = appendStr(p, ",D:");
  p = appendInt(p, (int16_t)targetDistance);
  p = appendStr(p, ",H:");
  *p++ = humanDetected ? '1' : '0';
  *p = '\0';

  radio.transmit((uint8_t*)payload, strlen(payload));

  delay(2000);
}

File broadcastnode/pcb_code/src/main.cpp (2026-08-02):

#include <Arduino.h>
#include <SX1276.h>

#define LORA_CS PIN_PA4
#define LORA_RST PIN_PA6
#define LORA_DIO0 PIN_PA5

SX1276 radio;

char* appendStr(char* p, const char* s) {
  while (*s) *p++ = *s++;
  return p;
}

char* appendInt(char* p, int32_t v) {
  itoa(v, p, 10);
  return p + strlen(p);
}

void setup() {
  Serial.begin(115200);

  int16_t state = radio.begin(915000000L, LORA_CS, LORA_RST, LORA_DIO0);
  if (state != SX1276_ERR_NONE) {
    while (true);
  }
  radio.setSpreadingFactor(SX1276_SF_9);
}

void loop() {
  uint8_t buf[128];
  int16_t len = radio.receive(buf, sizeof(buf));

  if (len > 0) {
    int16_t rssi = radio.getRSSI();
    int8_t snr = radio.getSNR();

    char line[200];
    char* p = line;
    p = appendStr(p, "RSSI:");
    p = appendInt(p, rssi);
    p = appendStr(p, ",SNR:");
    p = appendInt(p, snr / 4);
    p = appendStr(p, ",LEN:");
    p = appendInt(p, len);
    p = appendStr(p, ",DATA:");
    for (int16_t i = 0; i < len; i++) {
      char c = (char)buf[i];
      *p++ = (c == '\n' || c == '\r') ? '?' : c;
    }
    *p = '\0';

    Serial.println(line);
  }
}

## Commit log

2026-08-02 Add detailed descriptions of PCBs and project structure
2026-08-07 Update README with learning and challenges sections
    Added sections on learning experiences and challenges faced during PCB design.
